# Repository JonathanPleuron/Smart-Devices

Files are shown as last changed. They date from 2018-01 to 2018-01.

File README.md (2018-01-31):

## Smart Gas Sensor

This project was realised in the IoT growing context. It introduces a solution of 
smart gas sensor using the emerging LoRa technology.

### Code 

See the arduino section for the sensor relative implementation (low level).
See the JAVA section for application (high level).

### Documentation

See documentation folder for global documentation about the project and useful datasheets

### PCB

A PCB was designed for the Smart sensor (Uses [KiCad](http://kicad-pcb.org/) free software)

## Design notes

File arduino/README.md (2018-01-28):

## Arduino Code (C++)

Arduino code of the "Smart gas sensor" project (for Arduino UNO(ATmega328P)).

```
lora_gaz.ino = arduino project for Arduino IDE
```

```
lora_gaz.cpp = arduino C++ file
```

NOTE: This work is licensed under the [Creative Commons Attribution](https://creativecommons.org/licenses/by-nc/4.0/.)

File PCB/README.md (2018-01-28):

## PCB conception

The PCB for the projet "Smart gas sensor" was designed using the free software Kicad.

### Presentation

See PCB_Kicad.pdf

### Sources

The available sources are :

	- Project_V1 : Kicad source files (Schematic, footprints, Netlist, PCB)
	- MyLib : Library for specifically designed components

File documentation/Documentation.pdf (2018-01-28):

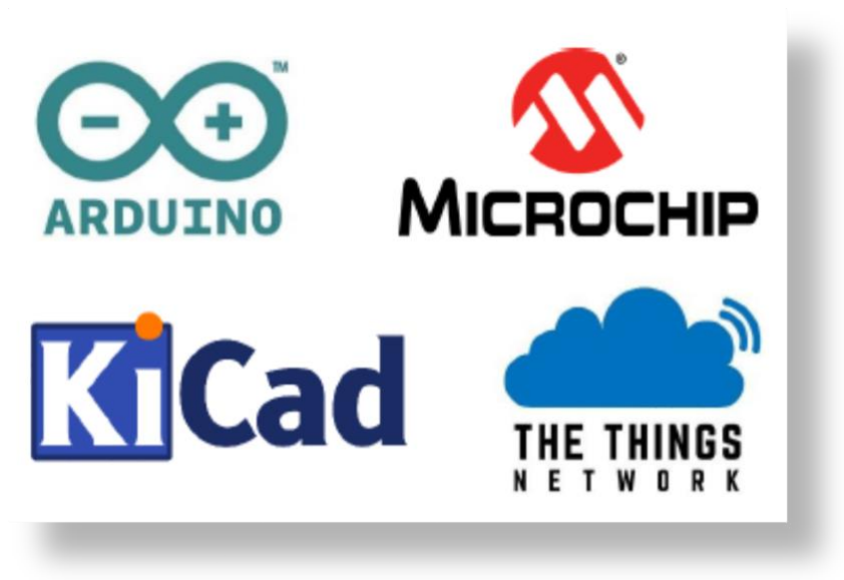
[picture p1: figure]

Jonathan PLEURON | Killian TESSIER

Capteur de gaz connecté - 5ISS – 2017/2018 1

# SMART DEVICES

## Capteur de gaz connecté

Date :

29/12/2017

Auteurs :

Jonathan PLEURON <pleuron@etud.insa-toulouse.fr> Killian TESSIER <tessier@etud.insa-toulouse.fr>

I. Introduction

Ce document a pour but de présenter le travail effectué durant le projet de conception d’un capteur de gaz intelligent et connecté.

Dans un premier temps, nous verrons le contexte général du projet avec son cahier des charges (philosophie du projet). L’architecture globale est décrite juste après, du capteur à la mise sur le réseau des informations en passant par toute la chaine de mesure et de traitement.
Ensuite pour chaque couche, la problématique est posée et la solution choisie présentée.
Enfin, la dernière partie conclue le document en présentant les problèmes rencontrés et en ouvrant sur des pistes d’amélioration.

Ce document fait guise à la fois de documentation sur l’état final du projet mais a pour but également de servir de base pour une éventuelle reprise du projet par des étudiants. Ainsi dans une optique open-source les documents relatifs au projet (code, documentation etc…) sont mis à disposition librement sur Github.

II. | Contexte et Cahier des charges
| Dans le cadre de l’émergence des objets connectés, nous avons travaillé sur le
développement d’un capteur de gaz connecté. Il s’agit ici de concevoir un capteur dit intelligent (smart device) c’est-à-dire qui doit :
- Mesurer la grandeur physique souhaitée (mesurande) : concentration de gaz
- Prendre en compte les grandeurs d’influences
- S’auto-étalonner voire s’autodiagnostiquer
- Consommer peu d’énergie afin de pouvoir être autonome
- Transmettre les données via un réseau sans fil
| Ce projet est réalisé dans un contexte open source. Le matériel (hardware) et les
logiciels (software) utilisés doivent être si possible open-source.

III. Chaine de mesure

Un smart device peut être décomposé en plusieurs blocs physiques ou logiques présentés ci-dessous

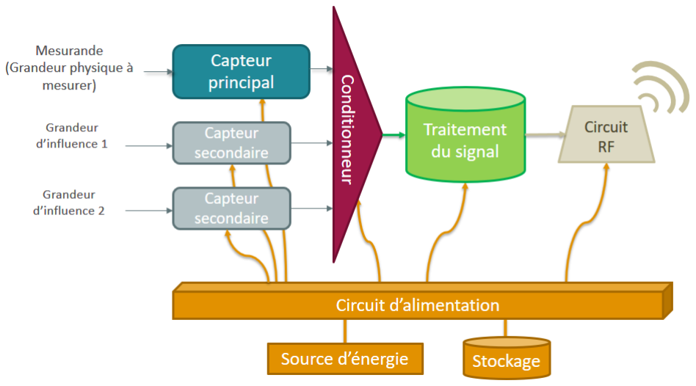
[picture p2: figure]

Fig 1 : Schéma bloc d’un smart device

Dans le cadre du projet le capteur utilisé est un capteur de gaz à base de nanoparticules de WO3 que nous avons réalisé en salle blanche (voir datasheet sur Github documentation/datasheets/GSWO3AIMe.pdf). Ce capteur mesure à la fois la concentration de gaz et la température (grandeur d’influence).
Le conditionnement du signal se fait de manière analogique et le traitement via une microcontrôleur ATmega328P (celui présent sur l’Arduino UNO).
La transmission Radio Fréquence (sans fil) se fait en utilisant la technologie LoRa (Low Range Wide Area) via un module Microship RN2483A qui connecte le capteur au réseau TTN (https://www.thethingsnetwork.org/).
Enfin le capteur est autonome et puise son énergie d’un accumulateur Li-ion qui est rechargé par un panneau solaire.
Le schéma global du capteur de gaz intelligent est présenté ci-dessous :

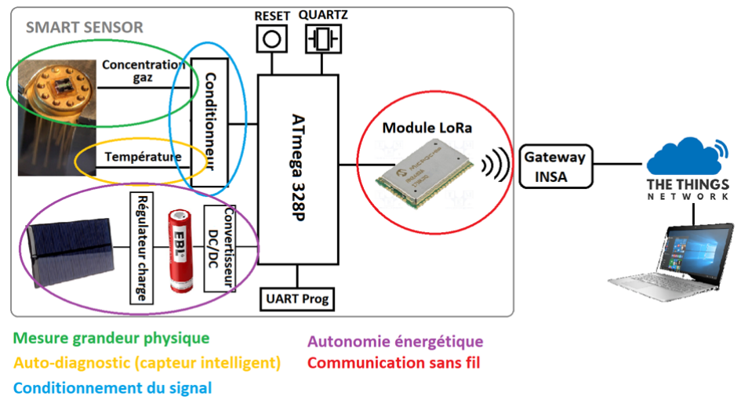
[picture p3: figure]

Fig 2 : Schéma bloc du capteur de gaz connecté

IV. | Acquisition des grandeurs physiques et conditionnement du signal
| L’acquisition des grandeurs physiques (concentration de gaz et température) est
réalisée par un seul capteur. Ce-dernier peut être vu comme deux impédances résistives :
- Rsensor = résistance proportionnelle à la concentration de gaz -> 10kΩ à 1GΩ
- Rtemp = résistance aluminium proportionnelle à la température du capteur
| -> 100-200Ω
| Les caractéristiques courant/tension de ces impédances sont détaillées dans la
datasheet du capteur. Les valeurs approximatives suffisent à concevoir le circuit de conditionnement du signal.
| Une troisième impédance, purement résistive (piste en poly-silicone), est présente
sur le capteur et sert à chauffer celui-ci pour le mettre à sa bonne température d’utilisation. La tension nécessaire pour faire chauffer cette résistance est de minimum 10V. C’est pourquoi un circuit de type booster de tension devra être ajouté au circuit qui repose sur une alimentation par accu de 3.7V.
| Les deux résistances vont être converties en tension via des montages de type
potentiométrique afin d’être reliées à deux entrées ADC (Analog to Digital Converter) du microcontrôleur. La résistance de température étant relativement faible elle sera juste insérée dans un pont diviseur avec une tension Vcc égale à la tension de référence de l’ADC. La résistance de mesure du gaz (Rsensor) elle est très grande et va poser des problèmes d’adaptation d’impédance si elle est directement connectée à l’ADC (Rmax = 10k Ω à l’entrée de l’ADC du ATmega328). C’est pourquoi on attaque plutôt un AOP (via un pont diviseur)

avec une impédance d’entrée tolérée bien plus grande et qui va amplifier la tension. On réalise un montage amplificateur non inverseur :

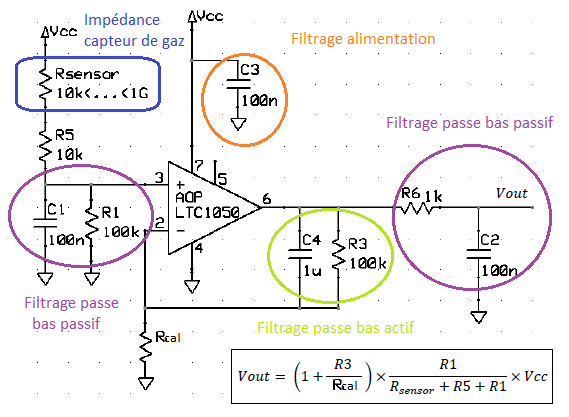
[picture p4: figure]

Fig 3 : Circuit de conditionnement pour la mesure de la concentration de gaz

On constate sur le schéma la présence de plusieurs filtres passe bas qui permettent notamment de couper le 50Hz très perturbant et d’éviter le repliement lors de l’échantillonnage.

Remarque : L’AOP utilisé doit être de type « low rail » (ex : LTC1050).

V. Traitement numérique (Microcontrôleur) et communication sans fil

Nous l’avons déjà évoqué, le traitement numérique se fait à l’aide d’un microcontrôleur ATmega328P, celui présent sur l’Arduino UNO. Attention à bien choisir le modèle avec le bootloader. Nous utilisons principalement deux fonctions du µC qui sont les convertisseurs analogiques numérique (CAN ou ADC) et les UARTs pour la liaison série avec le programmeur et pour la communication avec le module LoRa. Pour fonctionner le µC a aussi besoin d’un résonnateur et d’un bouton de reset.

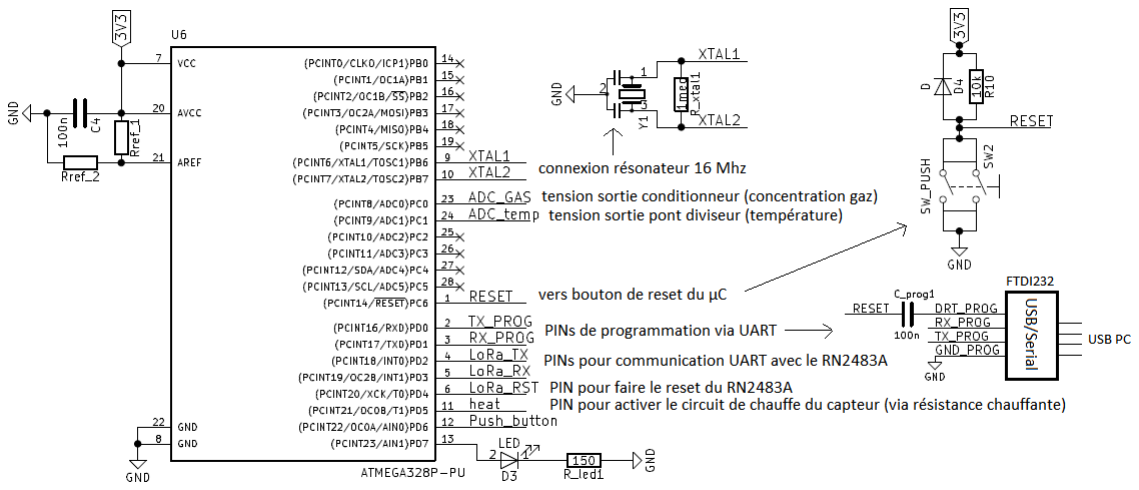
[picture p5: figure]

Fig 4 : Schéma électrique de la partie microcontrôleur

La programmation de l’ATmega peut se faire depuis l’IDE Arduino en utilisant un adaptateur USB/Série de type FTDI232. Les broches TX et RX du FTDI doivent être impérativement branchées aux pins D0 et D1 (UART physique) de l’ATMega et la broche DTR doit être relié au reset via un condensateur de 100pF.

La partie communication sans fil se fait à l’aide du module LoRa RN2483A de Microship qui inclue le circuit RF et un microcontrôleur gérant le stack réseau (LoRaWAN). La datasheet du module LoRa se trouve sur le Github (documentation/datasheets/Microship _RN2483A.pdf). Celui-ci communique via un port série à 57600 baud (par défaut) et se pilote via des commandes de trois types : mac, radio et système (détail des commandes dans
l’Application | Note | sur | Github | documentation/datasheets/RN2483A_AN.pdf). | Ces
commandes sont en fait une suite de caractères envoyés sur le port UART (ex : mac tx uncf 1 5 ,pour envoyer un ‘5’ sur le port 1 sans confirmation).

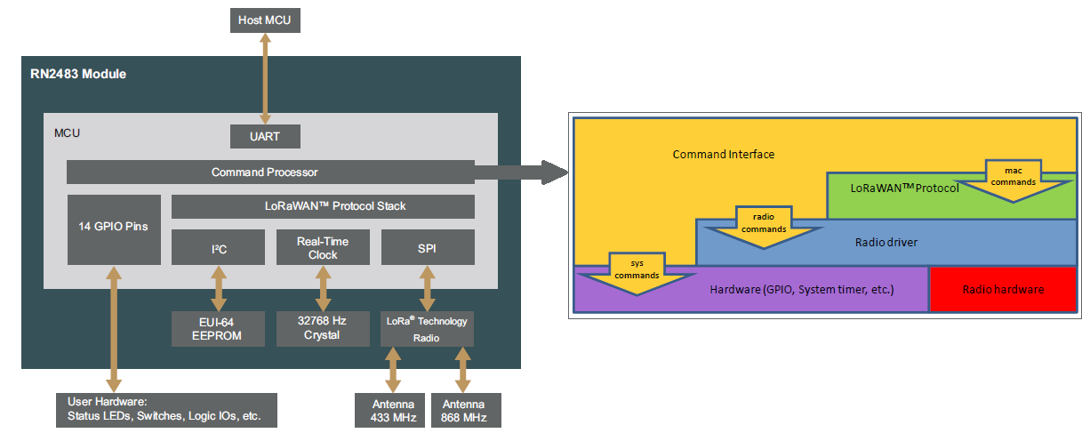
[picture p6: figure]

Fig 5 : Architecture logique du module LoRa RN2483A

Pour rappel la technologie LoRa utilise une architecture basée sur des devices émettant vers une gateway qui fait le relai vers un cloud (dans notre cas vers le réseau TheThingsNetwork). Afin de tester le module, on peut effectuer une communication pair-à-pair entre deux modules sans passer par la gateway. Pour cela on utilise directement les commandes de type radio. Pour effectuer ces tests et visualiser les réponses des modules on peut utiliser un terminal série comme Putty sous Windows ou Gtkterm sous Linux.

Fig 6 : Envoi d’un « hello » (0x48656C6C6F) en Peer-To-Peer

Pour une communication avec le réseau TTN, nous passons par la gateway de l’INSA de Toulouse et utilisons la librairie TheThingsNetwork pour Arduino. Cette librairie masque la partie protocolaire du réseau LoRaWAN et permet de faire des envois vers TTN avec des commandes simples de type sendBytes().

Avant d’envoyer des commandes, pour lier le code tournant sur l’ATmega et le réseau TTN il faut passer par la création d’une application en s’enregistrant sur le réseau. Pour cela, il faut suivre des tutoriels sur le site de TTN. Une fois enregistré sur le réseau TTN, le code est lié à l’application via une adresse d’appareil (devAddr), une clé de session réseau (nwkSKey) et une clé de session applicative (appSKey). Ce triplet est valable pour une connexion de type ABP (Activation by personalization), la connexion en OTAA () est également possible (https://www.thethingsnetwork.org/forum/t/what-is-the-difference-between-otaa-and-abp-devices/2723 (https://www.thethingsnetwork.org/forum/t/what-is-the-difference-between-otaa-and-abp-devices/2723) pour voir la différence entre les deux modes de connexion ).

Le code source arduino se trouve sur le Github sous /Arduino.

VI. | Traitement logiciel et réseau
| Pour récupérer les données du capteur présentes sur TTN, nous avons choisi d’utiliser
java avec MQQT, une des APIs conseillées par TTN pour récupérer nos données, et qui est très utilisée dans le domaine de l’IoT. MQTT est un protocole M2M très léger qui fonctionne à partir de publication et de souscriptions à des topics.
| Pour cela nous avons utilisé la librairie fournie par TTN qui fournit un client qui
implémente la librairie paho mqtt. Avec elle, on peut facilement se connecter à notre application TTN, à l’aide de notre AppID et de notre Access Key. Ainsi on peut initier une connexion à notre TTN et définir les actions à mettre en place lors de la réception de messages sur nos topics, l’activation, la déconnection, etc.

Les payloads reçus sont sous forme d’objets Json, facilement découplables à l’aide la librairie de manipulation de Json pour java : Jackson. Le capteur envoie à TTN 4 octets de données correspondant aux valeurs des ADC pour la mesure de gaz et de température. Une fois sur TTN la payload est formatée en JSON et on peut la décoder :

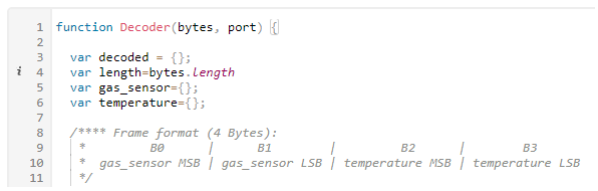
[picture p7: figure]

Fig 7 : Format d’un payload sur TTN

La payload est décodée (reconstruction des données) puis validée (elimination des valeurs erronées). Cela se fait via les fonctions decoder() et validator() de TTN (voir github dans /TTN).

Nous avons créé une simple application qui se connecte à notre application TTN et qui affiche de façon lisible les informations récoltées par le capteur en récupérant les valeurs depuis le Json. À partir de là, on peut facilement étendre notre application, stocker les données reçues dans des objets java pour y effectuer des traitements, des statistiques et y ajouter une IHM.

Fig 8 : Code de connexion à l’application TTN

Le code complet est disponible sur Github dans /JAVA.

Remarque importante :

Pour ce projet les données recueillies par les capteurs, à savoir les valeurs numériques sur 10 bits correspondantes aux valeurs analogiques des capteurs de température et gaz, sont envoyées directement sur TTN. Cela limite le calcul au niveau du device et donc la consommation d’énergie mais celui-ci n’est plus réellement « intelligent ». Il ne fait aucun traitement. Pour la suite il faudra que ces valeurs soit traitées (conversions valeur numérique->concentration gaz/température, élimination des valeurs aberrantes, effet de la température sur le calcul de la concentration gaz, … ). Cette partie n’a pas été faite par manque de temps.

VII. | Consommation et Source d’énergie
| Dans le but de rendre notre appareil autonome en énergie, nous avons décidé de le
mettre sur batterie. Le dispositif est alimenté par une accumulateur 3.7V Li-ion qui offre une grande autonomie avec une capacité de 3000mAh. Nous utilisons un modèle de chez EBL qui a pour avantage d’être protégé contre les courts-circuits.
| Les batteries Li-ion doivent suivre un cycle particulier de charge, c’est pourquoi il faut
utiliser des circuits de charge dédiés comme le TP4056 présent sur le module XCSOURCE.
| L’énergie provient d’un panneau solaire 5-6V de 1W. Enfin la tension nécessaire à chauffer le capteur est générée par un convertisseur DC-

DC (WINGONEER XL6009) de type boost qui peut produire une tension entre jusqu’à 30V.

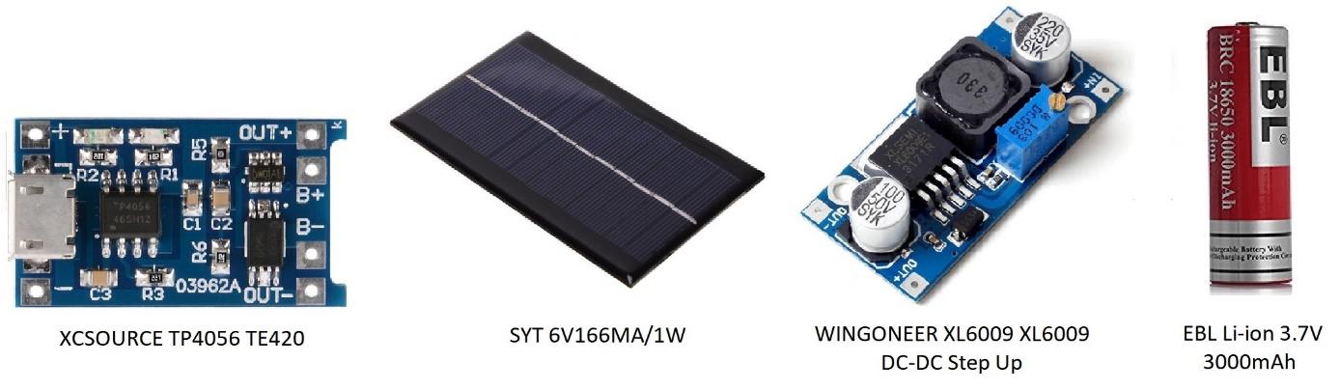
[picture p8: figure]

Fig 9 : Composants et kits utilisés pour alimenter le capteur connecté

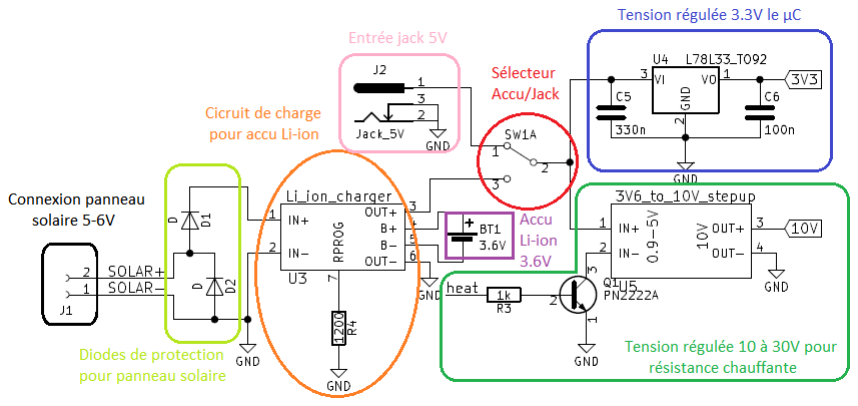
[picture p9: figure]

Fig 10 : Circuit électronique d’alimentation

VIII. Réalisation du PCB

Pour ce projet nous avons réalisé un PCB sur le logiciel libre Kicad. Une présentation (PowerPoint) du PCB ainsi que les fichiers sources sont disponibles sur le Github (/PCB).

IX. Problèmes rencontrés et améliorations possibles

Durant ce projet nous avons rencontrés quelques problèmes pouvant être résolus.

- La connexion en mode OTAA n’a pas fonctionné.
- Le compteur sur TTN doit être réinitialisé à chaque fois sinon les données ne sont pas
| reçues (comportement un peu aléatoire). Il faut identifier la source du problème ou faire en sorte d’automatiser la remise à zéro.
- Le panneau solaire semble délivrer trop peu de courant. Envisager un circuit
| d’adaptation/contrôle d’impédance ou prendre un panneau plus puissant.
- Le PCB peut être amélioré. En utilisant des composants directement à la place des
| kits la taille peut être réduite. Le module RN2483A peut être également souder directement sans passer par le shield.

Quelques autres améliorations peuvent être effectuées :

- Les PINs choisis peuvent être modifiés notamment en changeant les pin 2 et 3 qui
| servent aux interruptions de l’ATmega.
- Le code Arduino peut être amélioré en ajoutant des systèmes de détection d’erreur
| ou d’exceptions. Egalement, dans une logique de programmation orientée objet, les méthodes utilisées dans le loop() peuvent être déplacées dans des classes C++.
- On peut rajouter une IHM à notre application, avec des graphiques par exemple pour
| suivre l’évolution des données récoltées au cours du temps.

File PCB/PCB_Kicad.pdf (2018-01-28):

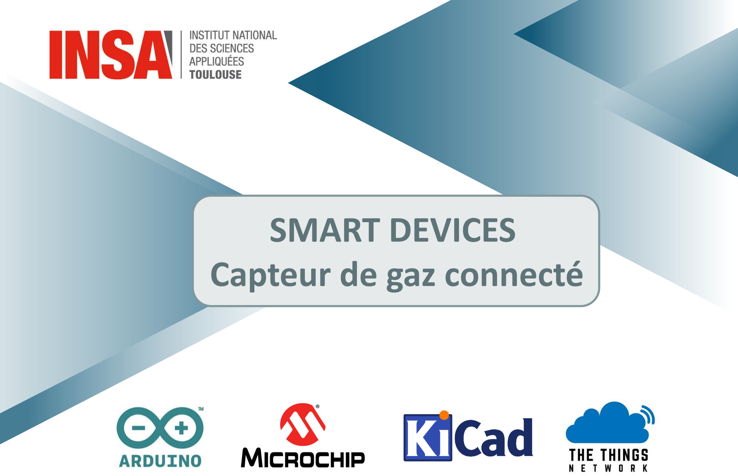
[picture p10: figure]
SMART DEVICES Capteur de gaz connecté

Killian TESSIER | Jonathan PLEURON | 5ISS 2017/2018

### MOSH : Schéma fonctionnel

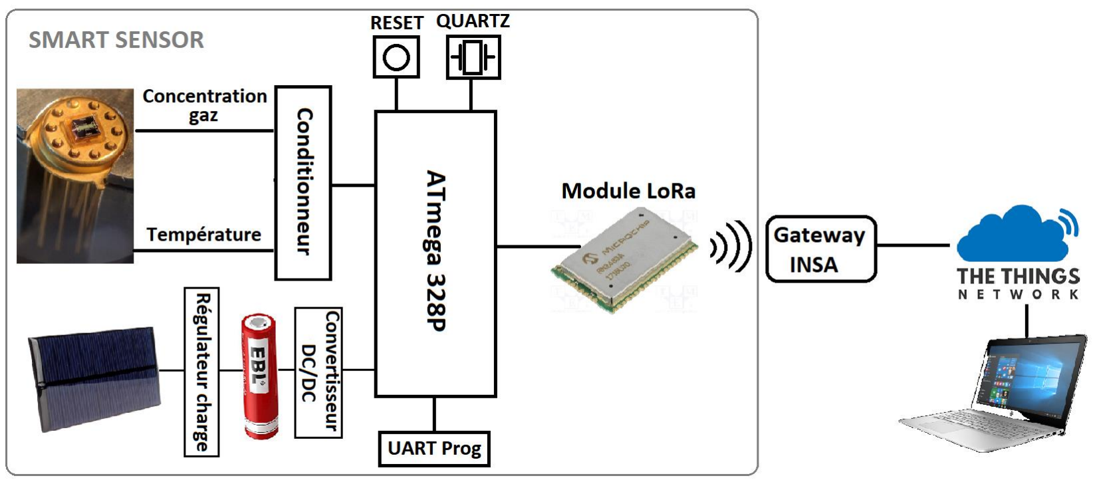
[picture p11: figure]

Killian TESSIER | Jonathan PLEURON | 5ISS 2017/2018

### MOSH : Schéma fonctionnel

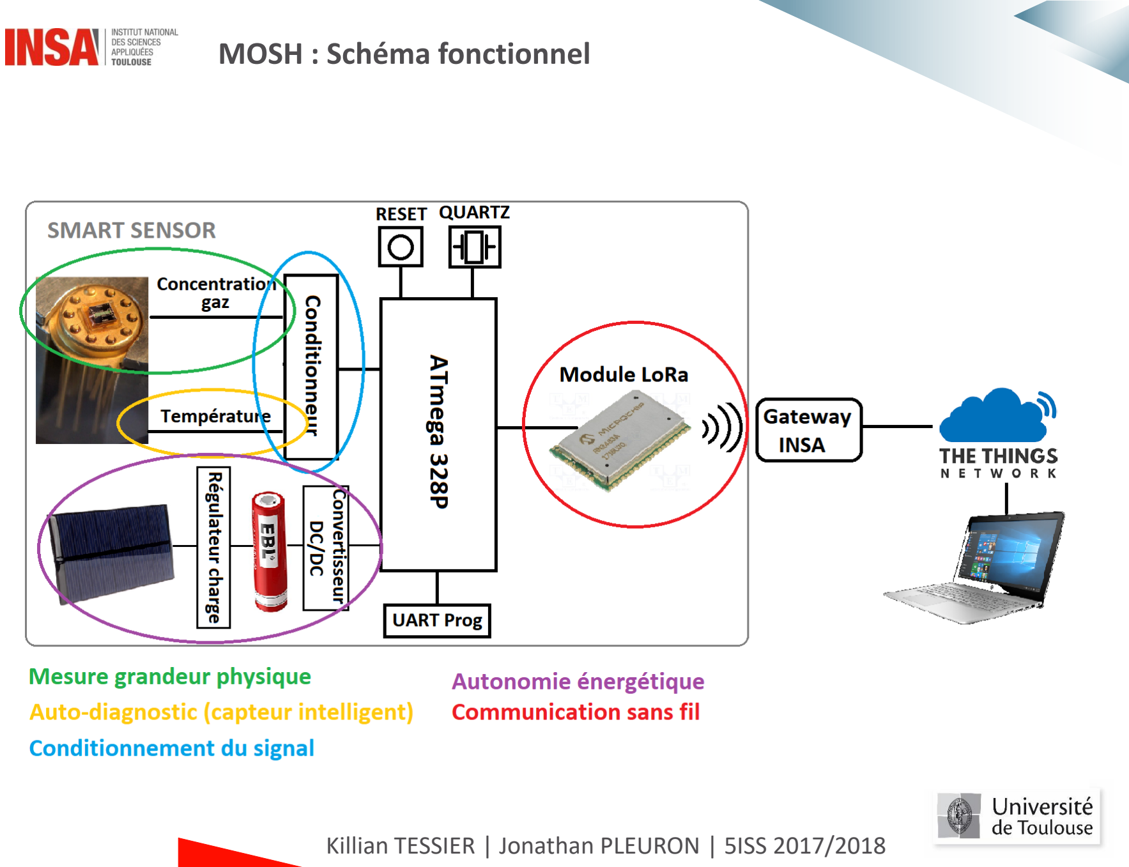
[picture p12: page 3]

### Kicad : Schéma électronique global

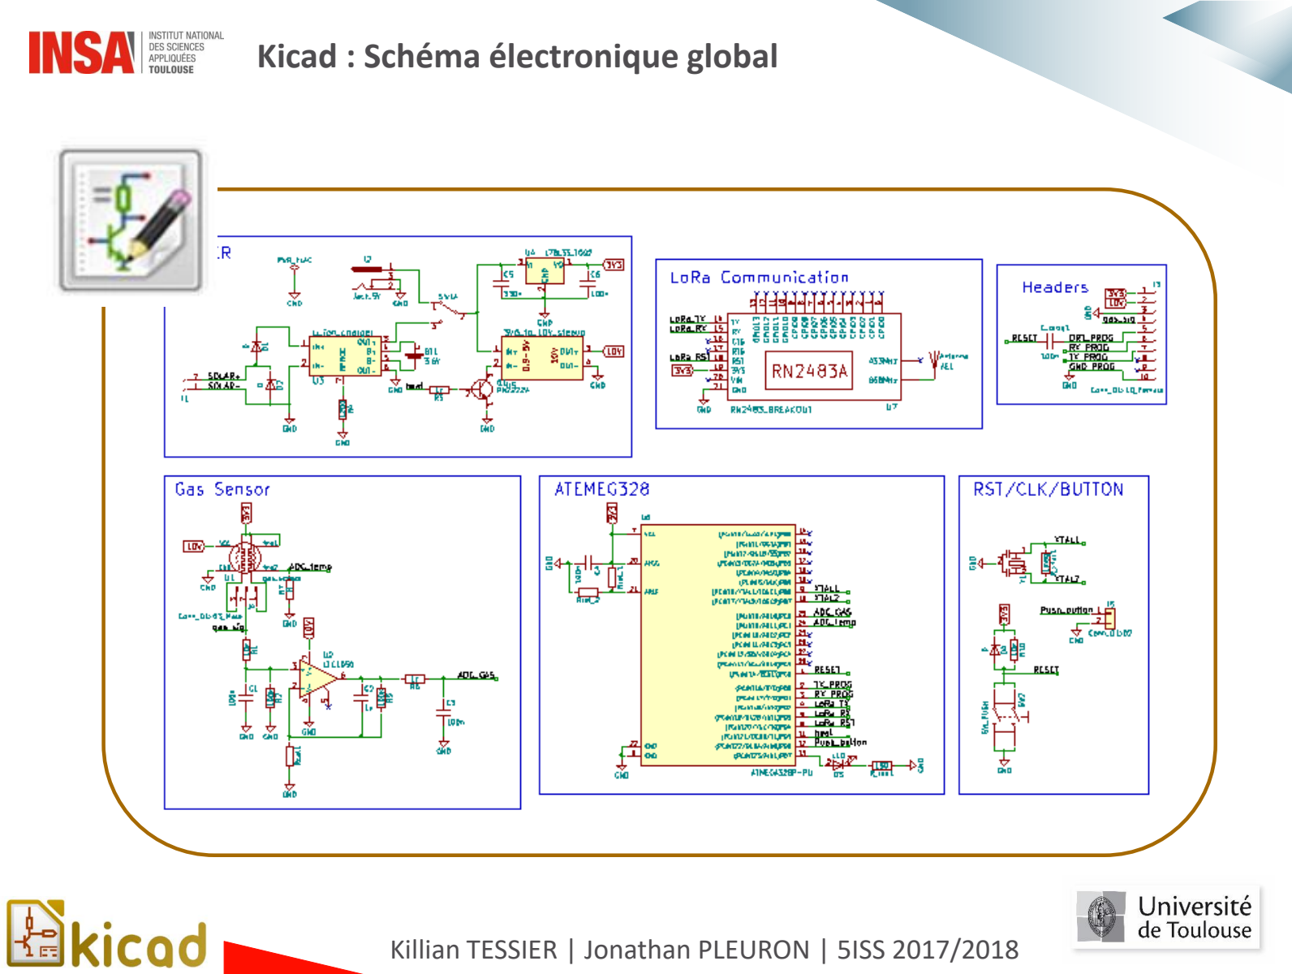
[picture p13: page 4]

### Kicad : Détail des blocs

### Alimentation

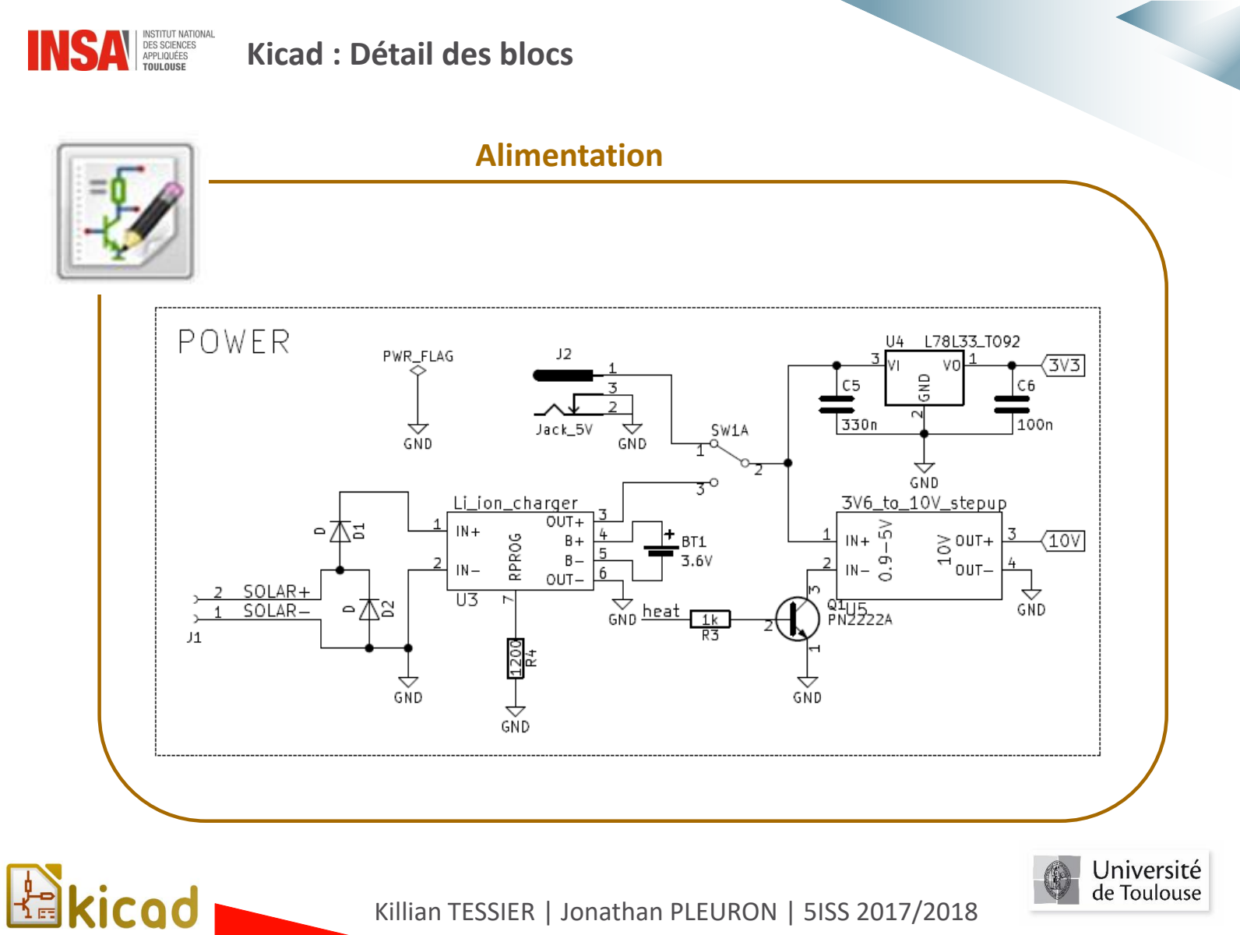
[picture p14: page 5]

### Kicad : Détail des blocs

### Capteur de GAZ

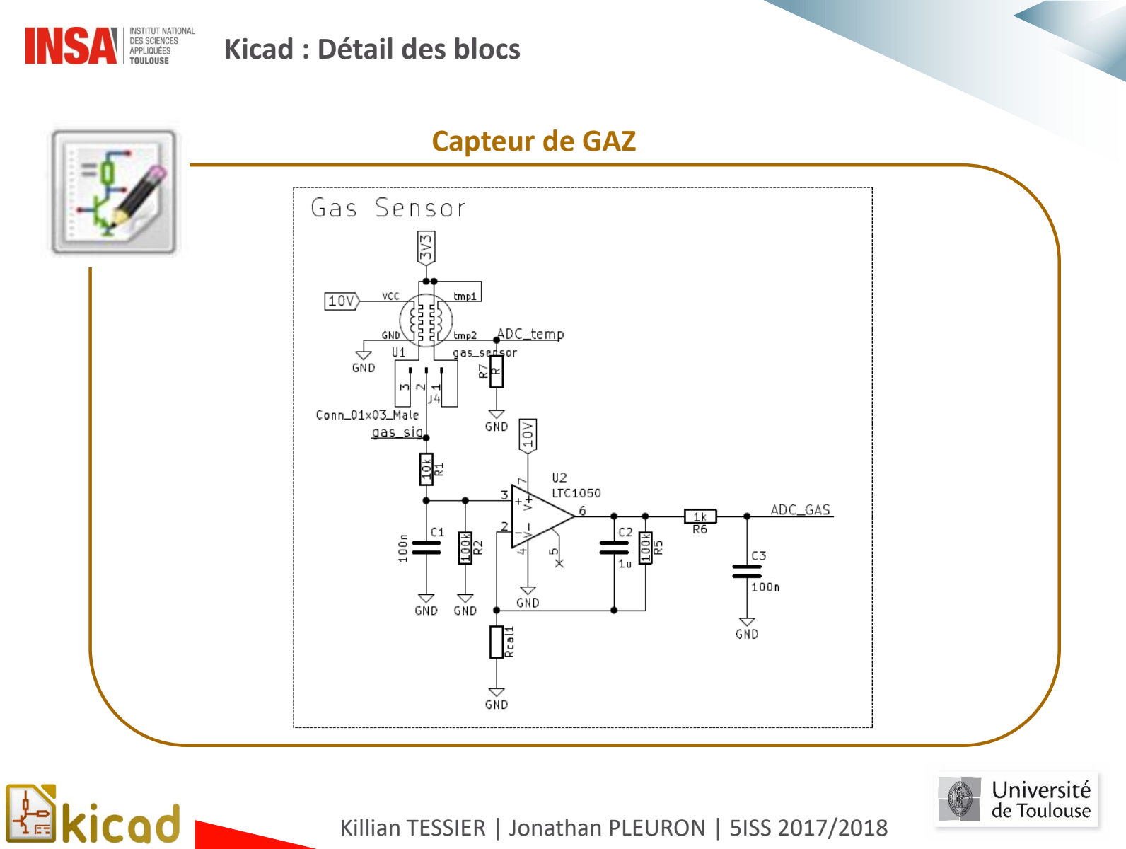
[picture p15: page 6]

### Kicad : Détail des blocs

### Module LoRa

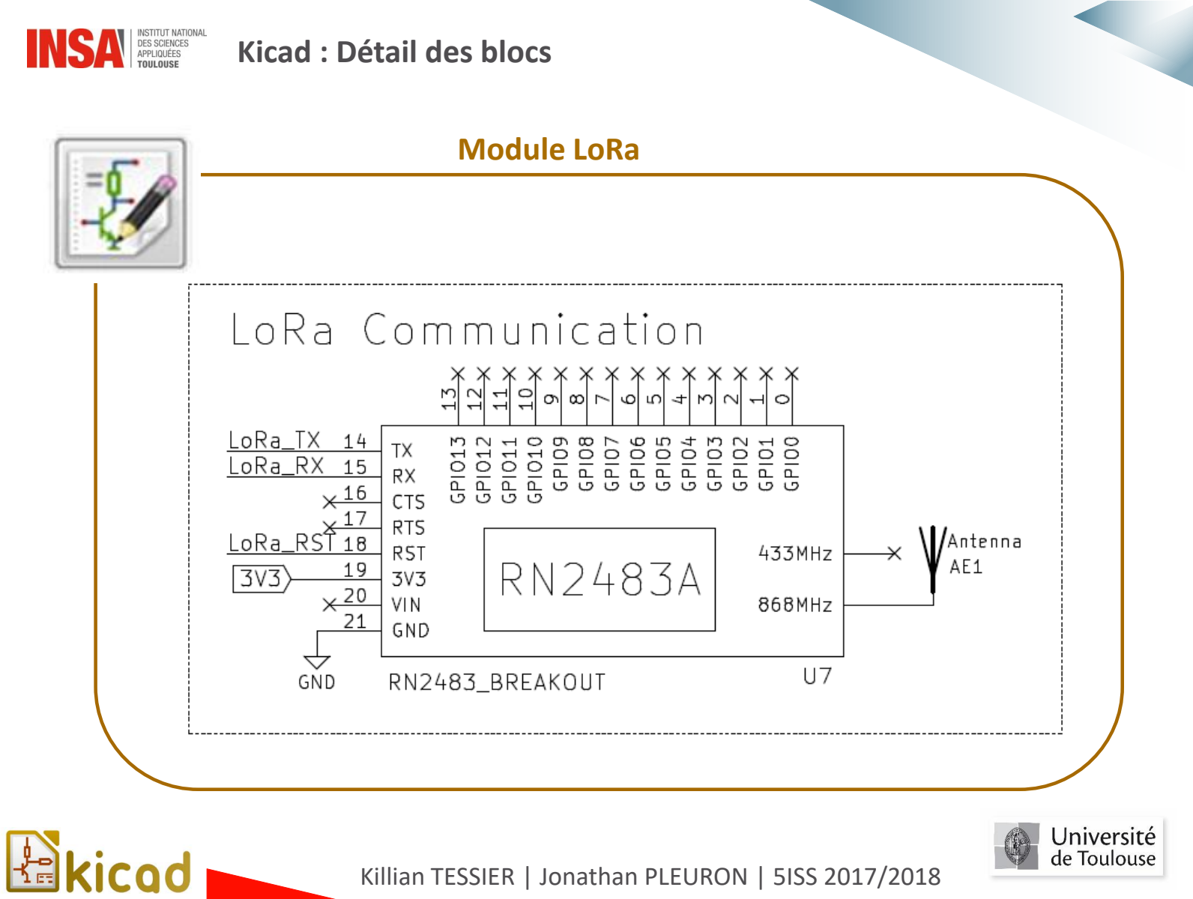
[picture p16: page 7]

### Kicad : Détail des blocs

### Microcontrolleur

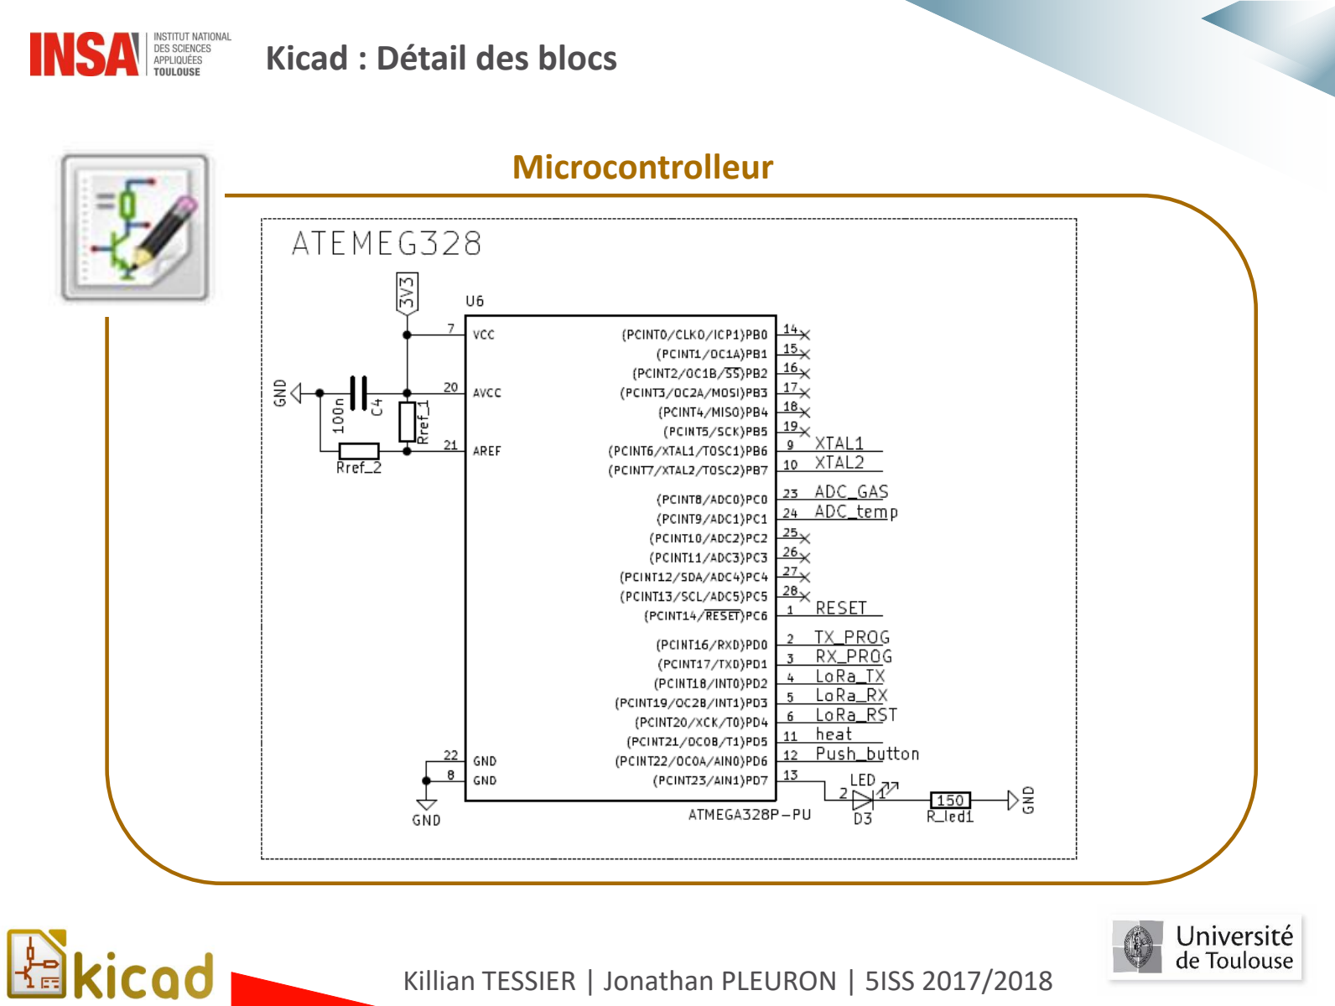
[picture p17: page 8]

### Kicad : Détail des blocs

### Connectiques et autres fonctions

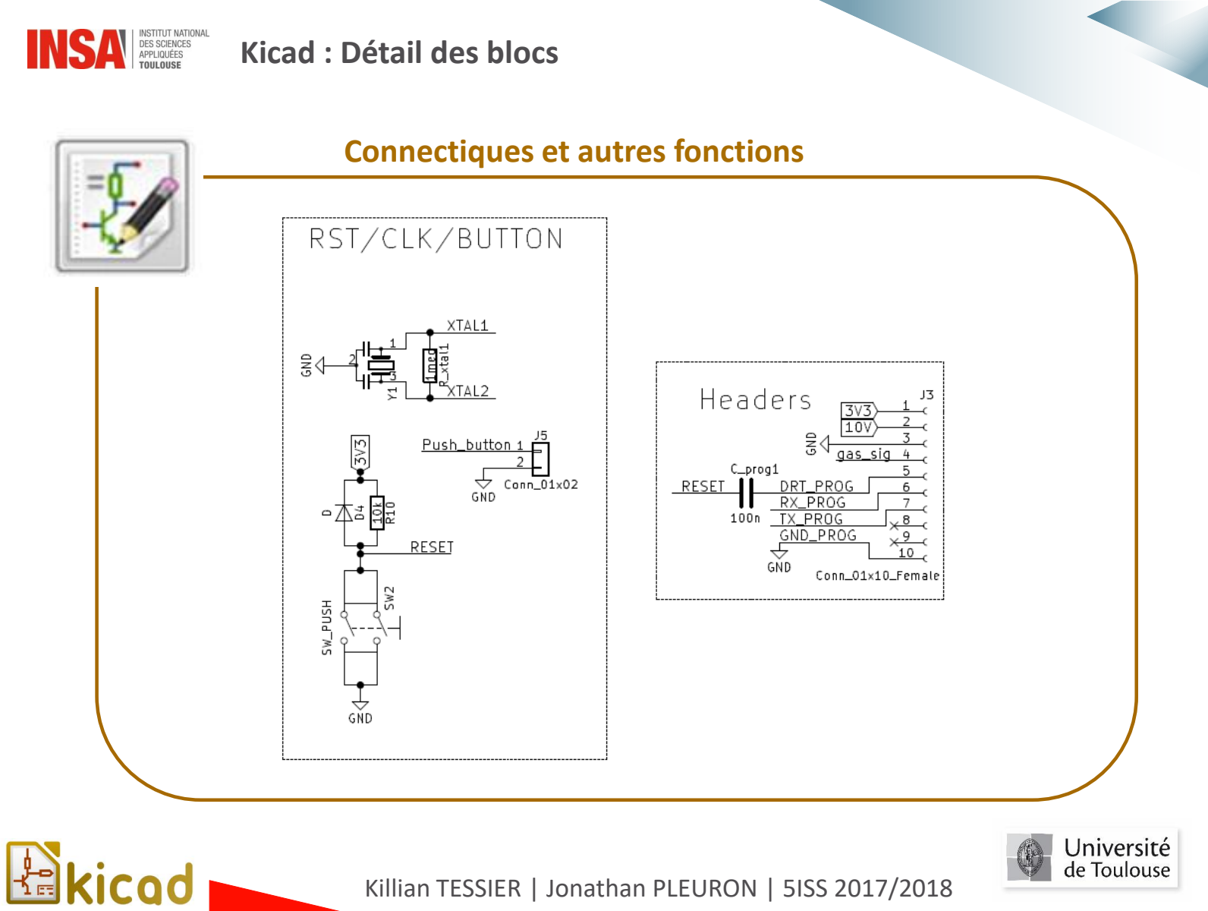
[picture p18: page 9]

### Kicad : Nouveaux composants

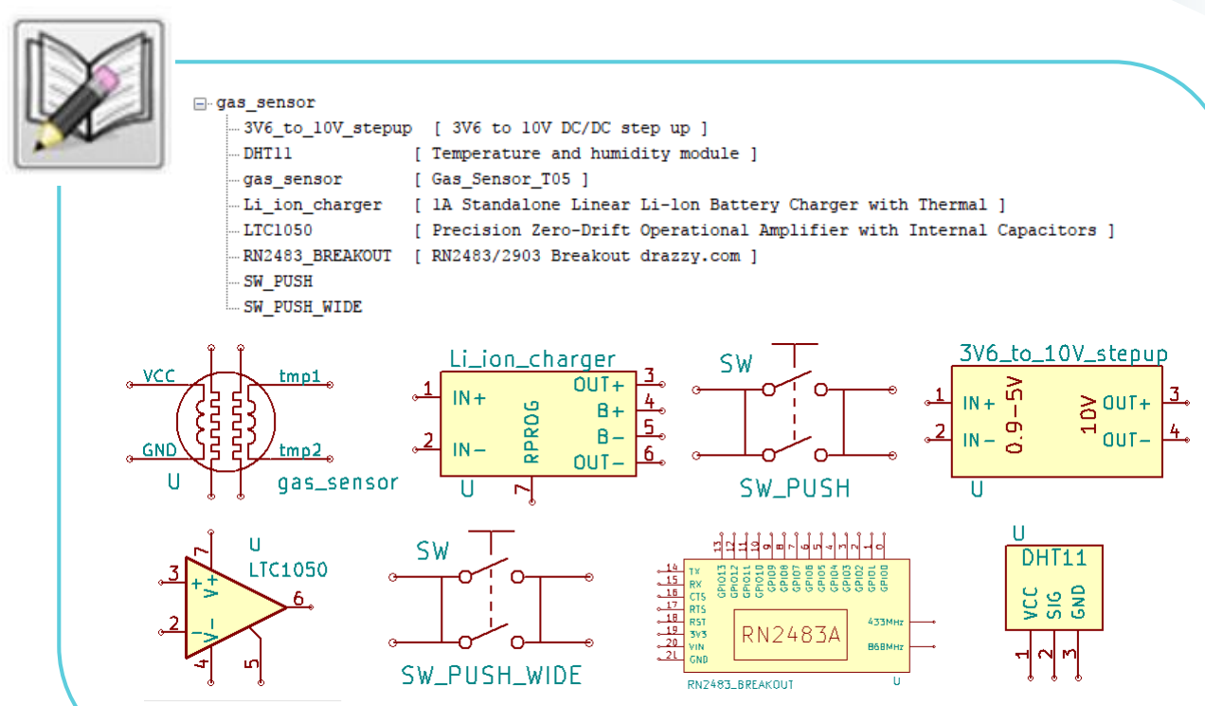
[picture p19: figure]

### Kicad : Nouvelles empreintes

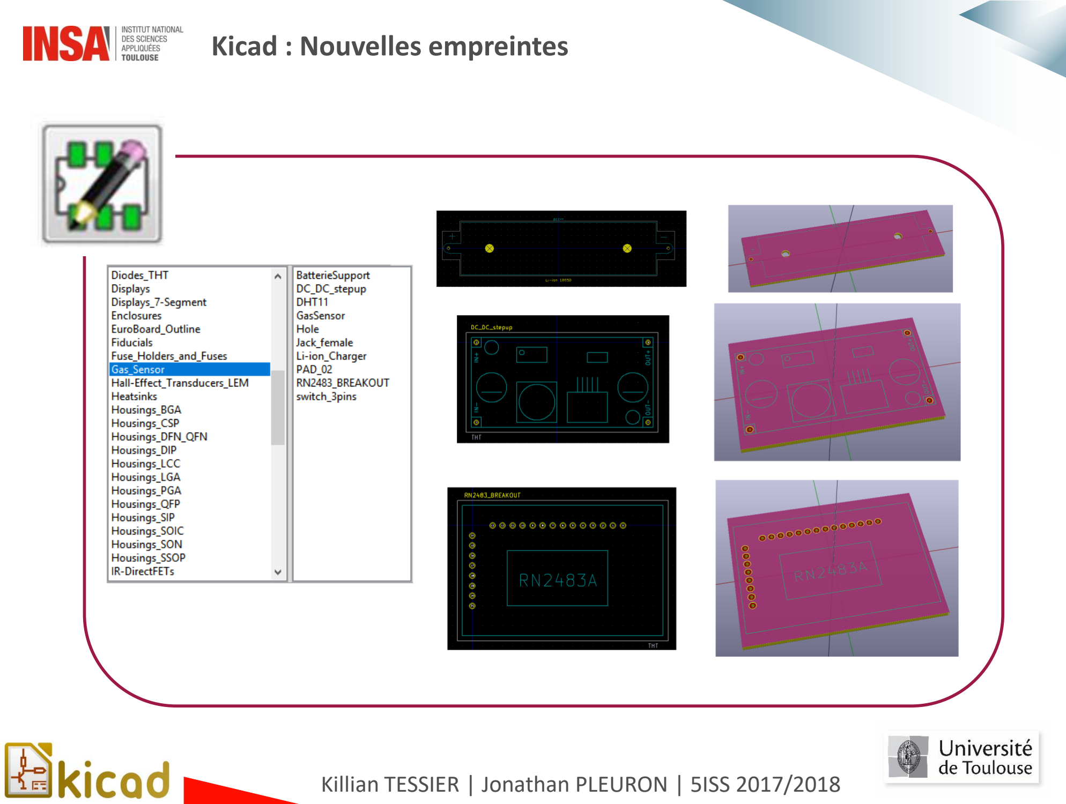
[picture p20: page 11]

### Kicad : PCB

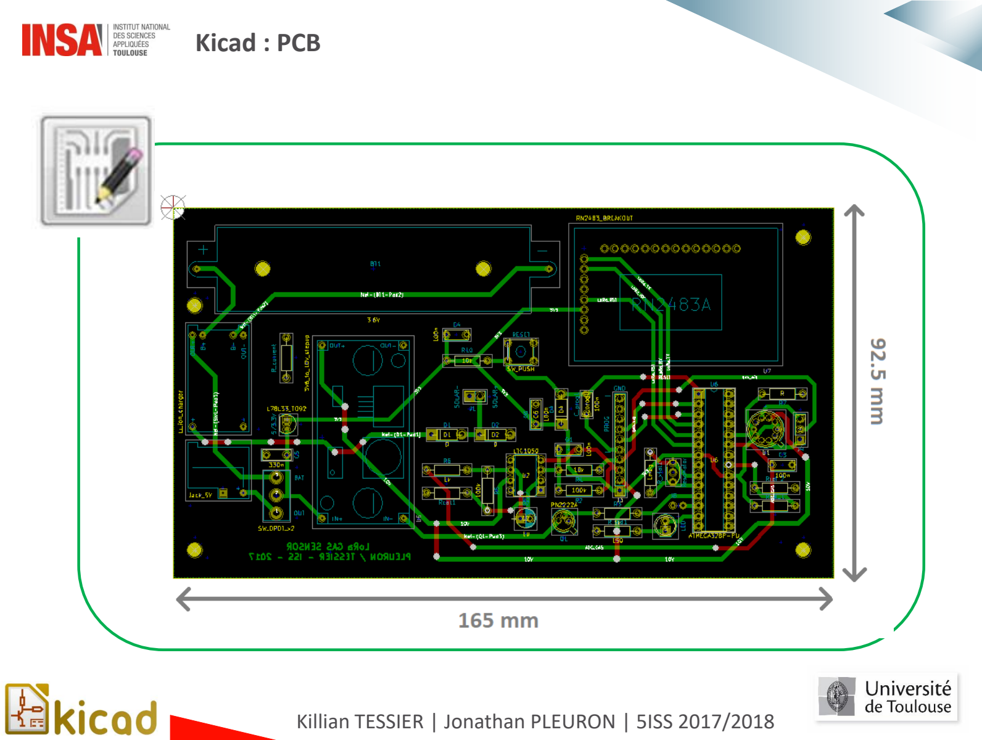
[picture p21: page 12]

### Kicad : PCB

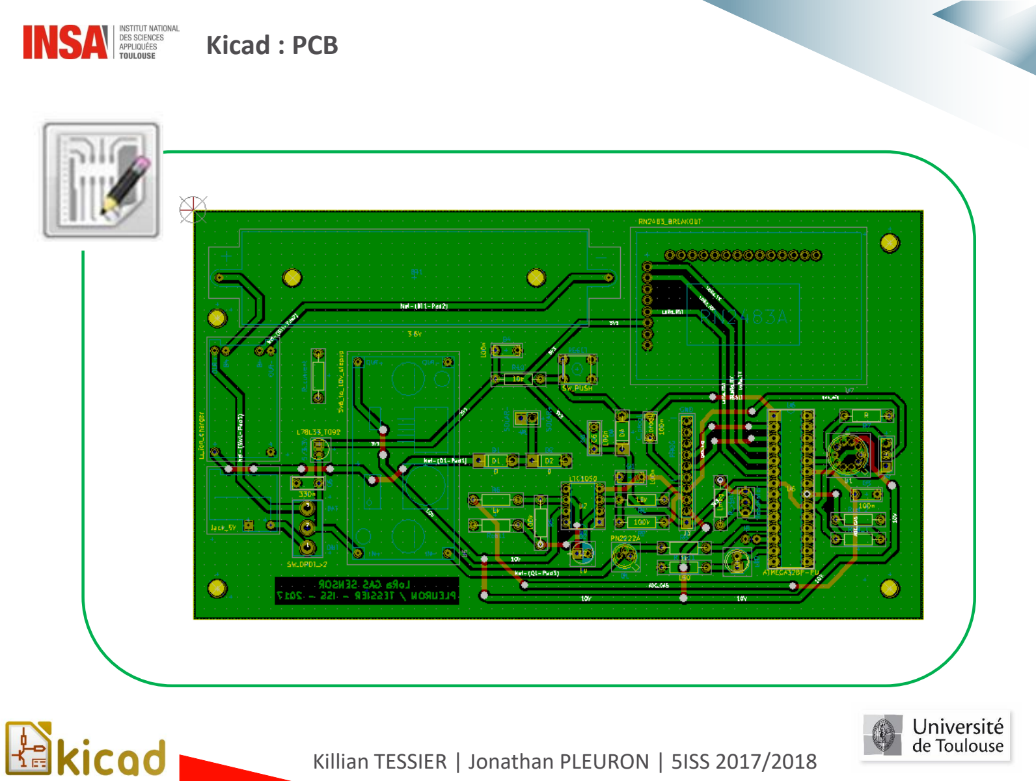
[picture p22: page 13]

### Kicad : PCB

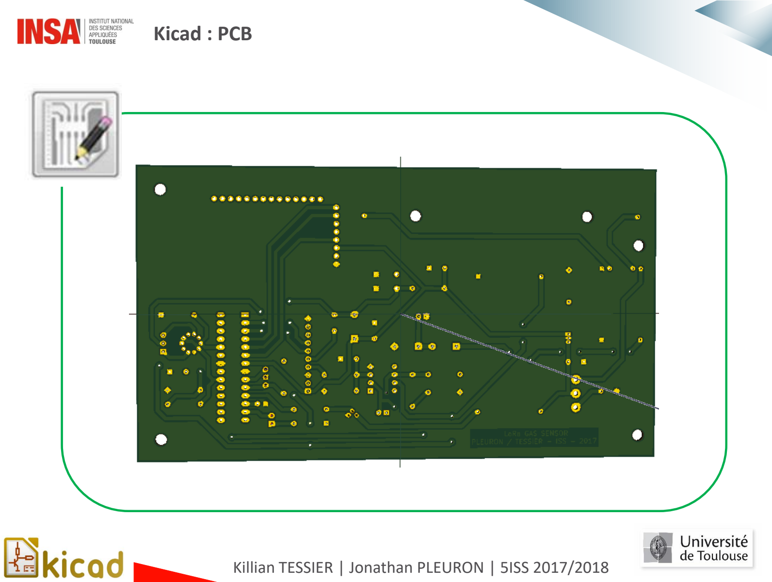
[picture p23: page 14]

### Kicad : PCB

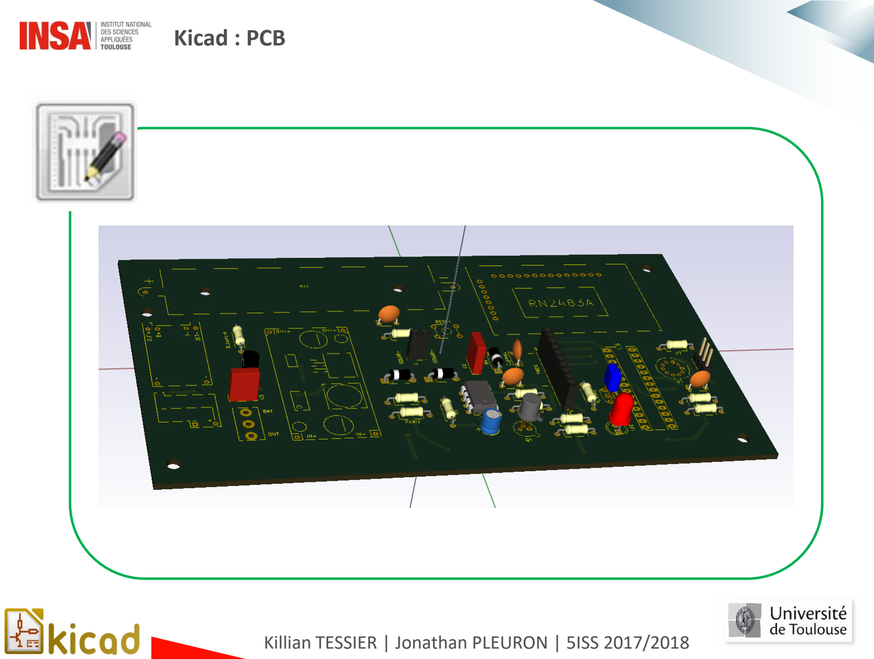
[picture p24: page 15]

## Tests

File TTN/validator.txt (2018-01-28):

function Validator(converted, port) {
  // Return false if the decoded, converted
  // message is invalid and should be dropped.

  if ((port != 1) || (converted.gas_sensor.value<0)) {
    return false;
  }
  else{
    return true;
  }
}

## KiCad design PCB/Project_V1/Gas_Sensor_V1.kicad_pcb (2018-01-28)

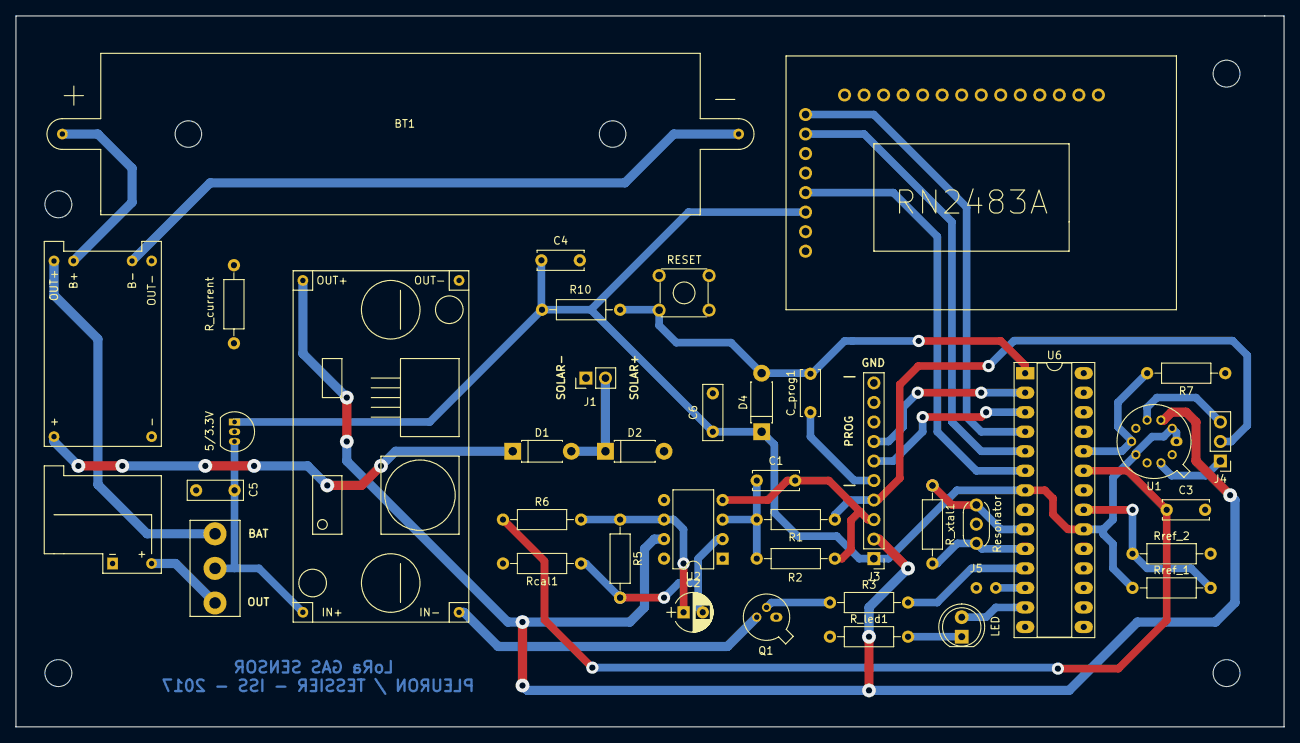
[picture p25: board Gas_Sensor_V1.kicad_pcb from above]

Board: 2 copper layers, 165.0 x 92.5 mm, 38 parts (0 on the bottom side), 29 nets.

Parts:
5/3.3V: L78L33_TO92; TO-92_Inline_Narrow_Oval
BT1: 3.6V; BatterieSupport
C1, C3, C4: 100n; C_Disc_D6.0mm_W2.5mm_P5.00mm
C2: 1u; CP_Radial_D5.0mm_P2.50mm
C5: 330n; C_Rect_L7.2mm_W2.5mm_P5.00mm_FKS2_FKP2_MKS2_MKP2
C6: 100n; C_Rect_L7.2mm_W2.5mm_P5.00mm_FKS2_FKP2_MKS2_MKP2
C_prog1: 100n; C_Disc_D6.0mm_W2.5mm_P5.00mm
D1, D2: D; D_DO-41_SOD81_P7.62mm_Horizontal
D4: D_DO-41_SOD81_P7.62mm_Horizontal
J1: Socket_Strip_Straight_1x02_Pitch2.54mm
J3: Socket_Strip_Straight_1x10_Pitch2.54mm
J4: Pin_Header_Straight_1x03_Pitch2.54mm
J5: PAD_02
LED: LED_D5.0mm
Q1: PN2222A; TO-18-3
R1, R10: 10k; R_Axial_DIN0207_L6.3mm_D2.5mm_P10.16mm_Horizontal
R2, R5: 100k; R_Axial_DIN0207_L6.3mm_D2.5mm_P10.16mm_Horizontal
R3, R6: 1k; R_Axial_DIN0207_L6.3mm_D2.5mm_P10.16mm_Horizontal
R7: R; R_Axial_DIN0207_L6.3mm_D2.5mm_P10.16mm_Horizontal
RESET: SW_PUSH; SW_TH_Tactile_Omron_B3F-10xx
R_current: R_Axial_DIN0207_L6.3mm_D2.5mm_P10.16mm_Horizontal
R_led1: 150; R_Axial_DIN0207_L6.3mm_D2.5mm_P10.16mm_Horizontal
R_xtal1: 1meg; R_Axial_DIN0207_L6.3mm_D2.5mm_P10.16mm_Horizontal
Rcal1: R_Axial_DIN0207_L6.3mm_D2.5mm_P10.16mm_Horizontal
Resonator: Resonator-3pin_w6.0mm_h3.0mm
Rref_1, Rref_2: R_Axial_DIN0207_L6.3mm_D2.5mm_P10.16mm_Horizontal
U1: TO-78-10
U2: LTC1050; DIP-8_W7.62mm
U5: 3V6_to_10V_stepup; DC_DC_stepup
U6: ATMEGA328P-PU; DIP-28_W7.62mm_Socket_LongPads
U7: RN2483_BREAKOUT

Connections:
3V3: 5/3.3V.1, C4.1, C6.1, D4.1, J3.1, R10.1, Rref_1.1, U1.1, U1.2, U1.7, U6.7, U6.20, U7.19
10V: J3.2, U1.3, U2.7, U5.3
/ADC_GAS: C3.1, R6.1, U6.23
/ADC_temp: R7.2, U1.6, U6.24
/DRT_PROG: C_prog1.1, J3.5
/LoRa_RST: U6.6, U7.18
/LoRa_RX: U6.5, U7.15
/LoRa_TX: U6.4, U7.14
/Push_button: J5.1, U6.12
/RESET: C_prog1.2, D4.2, R10.2, RESET.1, RESET.3, U6.1
/RX_PROG: J3.6, U6.3
/SOLAR+: D1.2, D2.1, J1.2
/TX_PROG: J3.7, U6.2
/XTAL1: R_xtal1.1, Resonator.1, U6.9
/XTAL2: R_xtal1.2, Resonator.3, U6.10
/gas_sig: J3.4, J4.2, R1.1
/heat: R3.2, U6.11
GND: 5/3.3V.2, C1.2, C3.2, C4.2, C5.2, C6.2, D2.2, J1.1, J3.3, J3.10, J5.2, Q1.1, R2.2, R7.1, RESET.2, RESET.4, R_current.2, R_led1.1, Rcal1.2, Resonator.2, Rref_2.2, U1.8, U2.4, U5.4, U6.8, U6.22, U7.21
unnamed: C1.1, R1.2, R2.1, U2.3
unnamed: C2.1, R5.1, R6.2, U2.6
unnamed: C2.2, R5.2, Rcal1.1, U2.2
unnamed: 5/3.3V.3, C5.1, U5.1
unnamed: LED.1, R_led1.2
unnamed: LED.2, U6.13
unnamed: J4.1, U1.9
unnamed: J4.3, U1.4
unnamed: Q1.2, R3.1
unnamed: Q1.3, U5.2
unnamed: Rref_1.2, Rref_2.1, U6.21

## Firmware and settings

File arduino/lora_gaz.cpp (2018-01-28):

/*

 LoRa gas sensor

 * Measures the analog value of two sensors :
    - gaz sensor (0-1.1V)
    - temperature sensor (0-3.3V)
 * Send value (4 bytes) by a LoRa module (Microchip RN2483A)to an application 
 on TheThingsNetwork (https://www.thethingsnetwork.org/) identifyed by :
  - a Device address : devAddr
  - a Network key : nwkSKey
  - an application key : appSKey
 * A heat() function permit turn on a pin to drive a heater circuit 
 for the gas sensor.
 * Device's sleeping most of the time to save energy and wakes up
 periodically to take these measures

 The circuit:
 - see schematic.jpg 
 
 created 22 Dec 2017
 by Jonathan Pleuron <pleuron@etud.insa-toulouse.fr>
    Killian Tessier  <tessier@etud.insa-toulouse.fr>

 This work is licensed under the Creative Commons Attribution 
 3.0 Unported License. To view a copy of this license, visit 
 https://creativecommons.org/licenses/by-nc/4.0/.

*/

#include <TheThingsNetwork.h>
#include <SoftwareSerial.h>
#include <MsTimer2.h>
#include <avr/sleep.h>
#include <avr/power.h>
#include <avr/wdt.h>

#define debugSerial       Serial
#define freqPlan          TTN_FP_EU868
#define byte_t            uint8_t
#define gas_sensor_pin    0   //Analog pin for the gas sensor
#define temp_sensor_pin   1   //Analog pin for the temperature sensor
#define DEFAULT_PORT      1   //TTN port
#define TX_PIN            2   //RN2483A RX pin
#define RX_PIN            3   //RN2483A TX pin
#define RST_PIN           4   //RN2483A Reset pin 
#define HEAT_PIN          5   //DC/DC boost enable pin

SoftwareSerial loraSerial(TX_PIN,RX_PIN); //Serial link with the LoRa module
volatile int f_wdt=0;
volatile int wdt_cpt=0;

/******* TTN app IDs ******/ 
/* We use a APB (Activation By Personalization) connection */
const char *devAddr = "2601124F";
const char *nwkSKey = "D727E89EA217AA295B32628E666E5249";
const char *appSKey = "2E1CE56CADD7F8F3D69663ACC7AEA22E";

TheThingsNetwork ttn(loraSerial, debugSerial, freqPlan);

/*************************************  LoRa functions ***************************************/

/* 
 * resetRN2483() - Reset the LoRa module
 */
void resetRN2483(){
    pinMode(RST_PIN, OUTPUT);
    digitalWrite (RST_PIN, LOW);
    delay(100);
    digitalWrite (RST_PIN, HIGH);  
    delay(100);
}

/* 
 * loraInit() - Initialize the LoRa module
 */
void loraInit(){
  resetRN2483();
  loraSerial.begin(57600);  //Serial link with the RN2483A
  MsTimer2::start();        //Timeout if ttn operation fails
  ttn.showStatus();         //Show RN2483A status
  MsTimer2::stop(); 
}

/* 
 * loraJoin() - Join TTN application
 */
void loraJoin(){
   ttn.personalize(devAddr,nwkSKey,appSKey);  //TTN join procedure (ABP mode)
}

/* 
 * loraSendBytes() - Send several bytes to the TTN application
 * 
 * @data: bytes to send
 * @length: numbre od byte to send
 * @port: TTN port
 */
int loraSendBytes(byte_t* data,int length, int port){ 
    return ttn.sendBytes(data, length,port);  //Send bytes to TTN
}

/* 
 * loraSendByte() - Send a single byte to the TTN application
 * 
 * @data: bytes to send
 * @length: numbre od byte to send
 * @port: TTN port
 */
int loraSendByte(byte_t* data,int port){
    return ttn.sendBytes(data,1,port);      //Send one byte to TTN
}

/* 
 * loraSendValues() - Send sensors values (gas + temperature) to the TTN application
 * 
 * @gas: gas sensor value
 * @temp: temperature sensor value
 * @port: TTN port
 */
int loraSendValues(int gas, int temp, int port){
      char data[4] ={gas >>8,gas & 0xFF,temp >>8,temp & 0xFF};
      return ttn.sendBytes(data,4,port);
}
/*********************************************************************************************/


/******************************** Timer/Sleep mode functions *********************************/

/* 
 * timeoutHandler() - Timeout handler
 */
void timeoutHandler(){
  debugSerial.println("Timeout !\n");
  MsTimer2::stop();
}

/* 
 * setupWatchdog() - Set up the watchdog
 */
void setupWatchdog(){
     cli();
     MCUSR &= ~(1<<WDRF);
     WDTCSR |= (1<<WDCE) | (1<<WDE);
     WDTCSR = 1<<WDP0 | 1<<WDP3;    //8.0 seconds
     WDTCSR |= _BV(WDIE);
     sei();
}
ISR(WDT_vect)
{
    //f_wdt=1;
    wdt_cpt++;
}

/* 
 * sleep_8s() - Turn Atemga328 into sleep mode for 8 seconds
 */
void sleep_8s(){
    set_sleep_mode(SLEEP_MODE_PWR_DOWN);
    sleep_enable();
    sleep_mode();
    // sleeping here
    sleep_disable();
    power_all_enable();
}

/* 
 * goToSleep() - Turn Atemga328 into sleep
 * 
 * @sec: sleeping duration in seconds (shall be a multiple of 8)
 */
void goToSleep(int sec){
    sec=sec>>3; // division by 8s
    wdt_cpt=0;  // reset counter
    int real_period = 8*sec;  //compute real period (8 multiple)
    debugSerial.print("Sleep (");
    debugSerial.print(real_period, DEC);
    debugSerial.print("s) ");
    while(wdt_cpt<sec){
      debugSerial.print("* ");
      delay(100);
      sleep_8s(); //go to sleep
      delay(100);
    }
    wdt_cpt=0;
    debugSerial.println("Wake up !");
}
/***************************************************************************************/


/***************************** Sensor/Actuator functions *******************************/

/* 
 * getGasValue() - Returns gas value (0-1023)
 */
int getGasValue(){
  analogReference(INTERNAL);//1.1V
  int val = analogRead(gas_sensor_pin);
  debugSerial.print("Gas value = ");
  debugSerial.print(val, DEC);
  debugSerial.println("/1023");
  return val ;
}

/* 
 * getTempValue() - Returns temperature value (0-1023)
 */
int getTempValue(){
  analogReference(DEFAULT);//5V
  int val = analogRead(temp_sensor_pin);
  debugSerial.print("Temperature value = ");
  debugSerial.print(val, DEC);
  debugSerial.println("/1023");
  return val;
}

/* 
 *heat() - Turns the HEAT_PIN on to activate the heating circuit
 *
 * @sec: heating duration in seconds
 */
void heat(int sec){
  digitalWrite (HEAT_PIN, HIGH);
  delay(1000*sec);
  digitalWrite (HEAT_PIN, LOW);
}
/***************************************************************************************/


void setup() {  
  debugSerial.begin(9600);    //Start serial debugging
  pinMode(HEAT_PIN, OUTPUT);  //Set up heat pin to out
  MsTimer2::set(15000,timeoutHandler); //Set up timeout timer
  f_wdt=0;
  setupWatchdog();  //Setup Watchdog for timeout
  loraInit();       //Init the LoRa module
  loraJoin();       //Join to TTN
}

void loop() {
  delay(100);
  heat(5);    //heat the sensor during 5s
  loraSendValues(getGasValue(),getTempValue(), 1); //Get the sensors value and send them to TTN
  goToSleep(120);   //Go in sleep mode during 2 min
}
